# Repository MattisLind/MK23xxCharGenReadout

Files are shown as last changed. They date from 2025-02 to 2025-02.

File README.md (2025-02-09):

# Mostek MK23XX Character Generator Readout

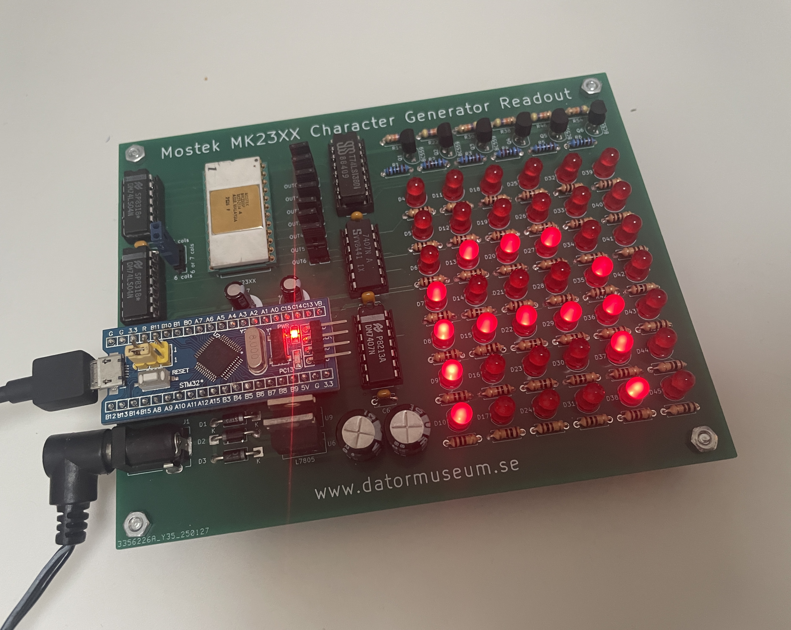
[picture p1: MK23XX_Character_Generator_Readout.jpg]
Mostek MK23XX Character Generator Readout device under opertion showing an A character


This device is used to read out the contents of early character generator MK23XX ROMs from Mostek. These devices is a bit special since they include a column counter so that the each column cannot be
accessed directly through external addressing pins.

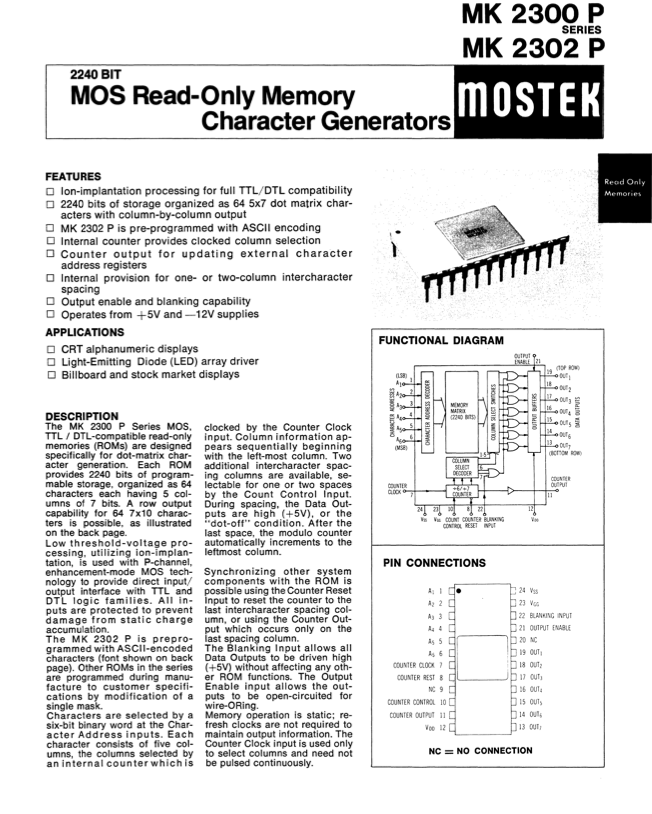
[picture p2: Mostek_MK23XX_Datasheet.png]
Mostek MK23XX Datasheet


The device has to be connected over USB (unless this section is commented out in the source code) and then it provide a dump of the contents of the ROM as hex as it cycles through all 64 characters.

```
CHAR0 COLUMN 0 VALUE 0
CHAR0 COLUMN 1 VALUE 0
CHAR0 COLUMN 2 VALUE 0
CHAR0 COLUMN 3 VALUE 0
CHAR0 COLUMN 4 VALUE 0
CHAR1 COLUMN 0 VALUE 7
CHAR1 COLUMN 1 VALUE 7
CHAR1 COLUMN 2 VALUE 7
CHAR1 COLUMN 3 VALUE 7
CHAR1 COLUMN 4 VALUE 7
CHAR2 COLUMN 0 VALUE 70
CHAR2 COLUMN 1 VALUE 70
CHAR2 COLUMN 2 VALUE 70
CHAR2 COLUMN 3 VALUE 70
CHAR2 COLUMN 4 VALUE 70
```

Please note that the contents of this example ROM is active low so that a binary 0 indicate a lit pixel. Depending if the outputs are active low or high the output driver can be 7407 or 7406 respectively.

## PCB

The first PCB had too small holes for the 24 pin ROM socket so it was not possible to fit a ZIF socket. I revised the PCB so that the new PCB have 1.0 mm holes rather than 0.8 mm. I think that this should work better but have not ordered any PCB to check. 

## Software

The software is an Arduino sketch. I have been using [Arduino Core STM32](https://github.com/stm32duino/Arduino_Core_STM32) library. The Bluepill is a STM32F103C6 and it is set to have USB enabled with serial support 

There is a #define SCROLL which can be set to either 0 or 1 if one want the fancier soft scroll rather than just showing each character.

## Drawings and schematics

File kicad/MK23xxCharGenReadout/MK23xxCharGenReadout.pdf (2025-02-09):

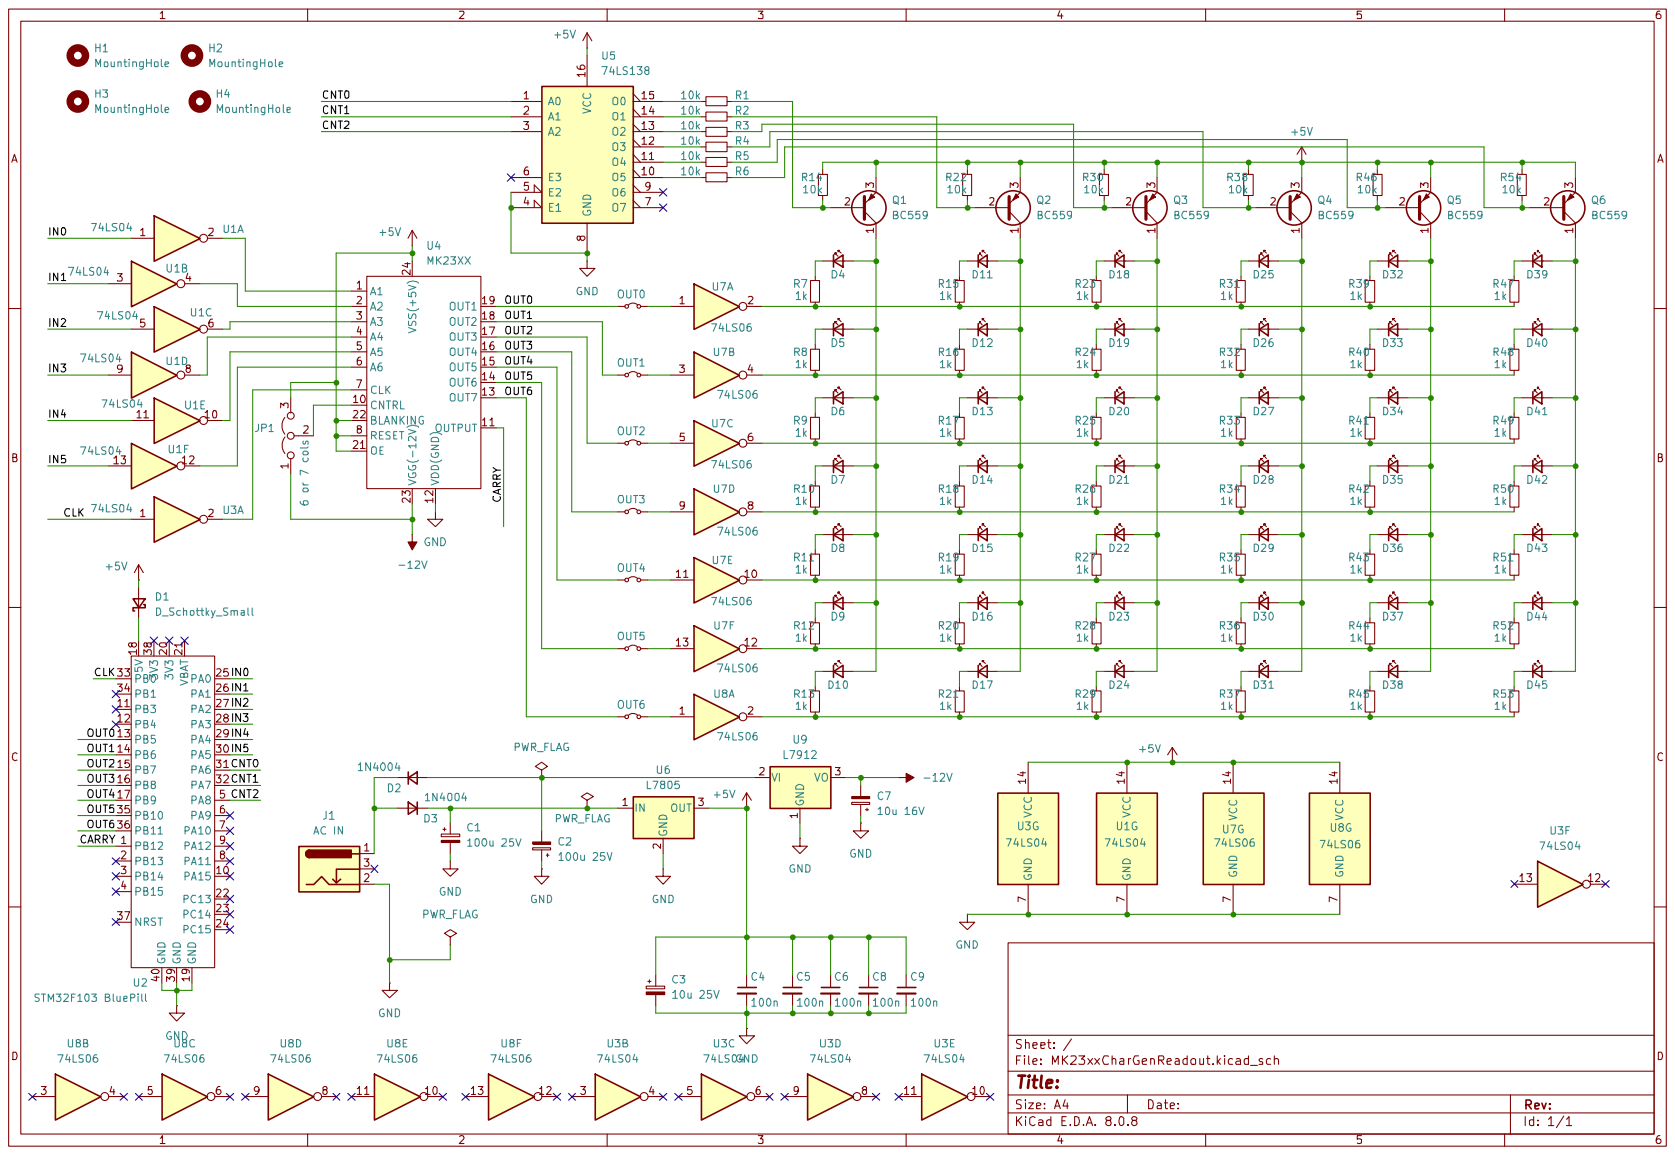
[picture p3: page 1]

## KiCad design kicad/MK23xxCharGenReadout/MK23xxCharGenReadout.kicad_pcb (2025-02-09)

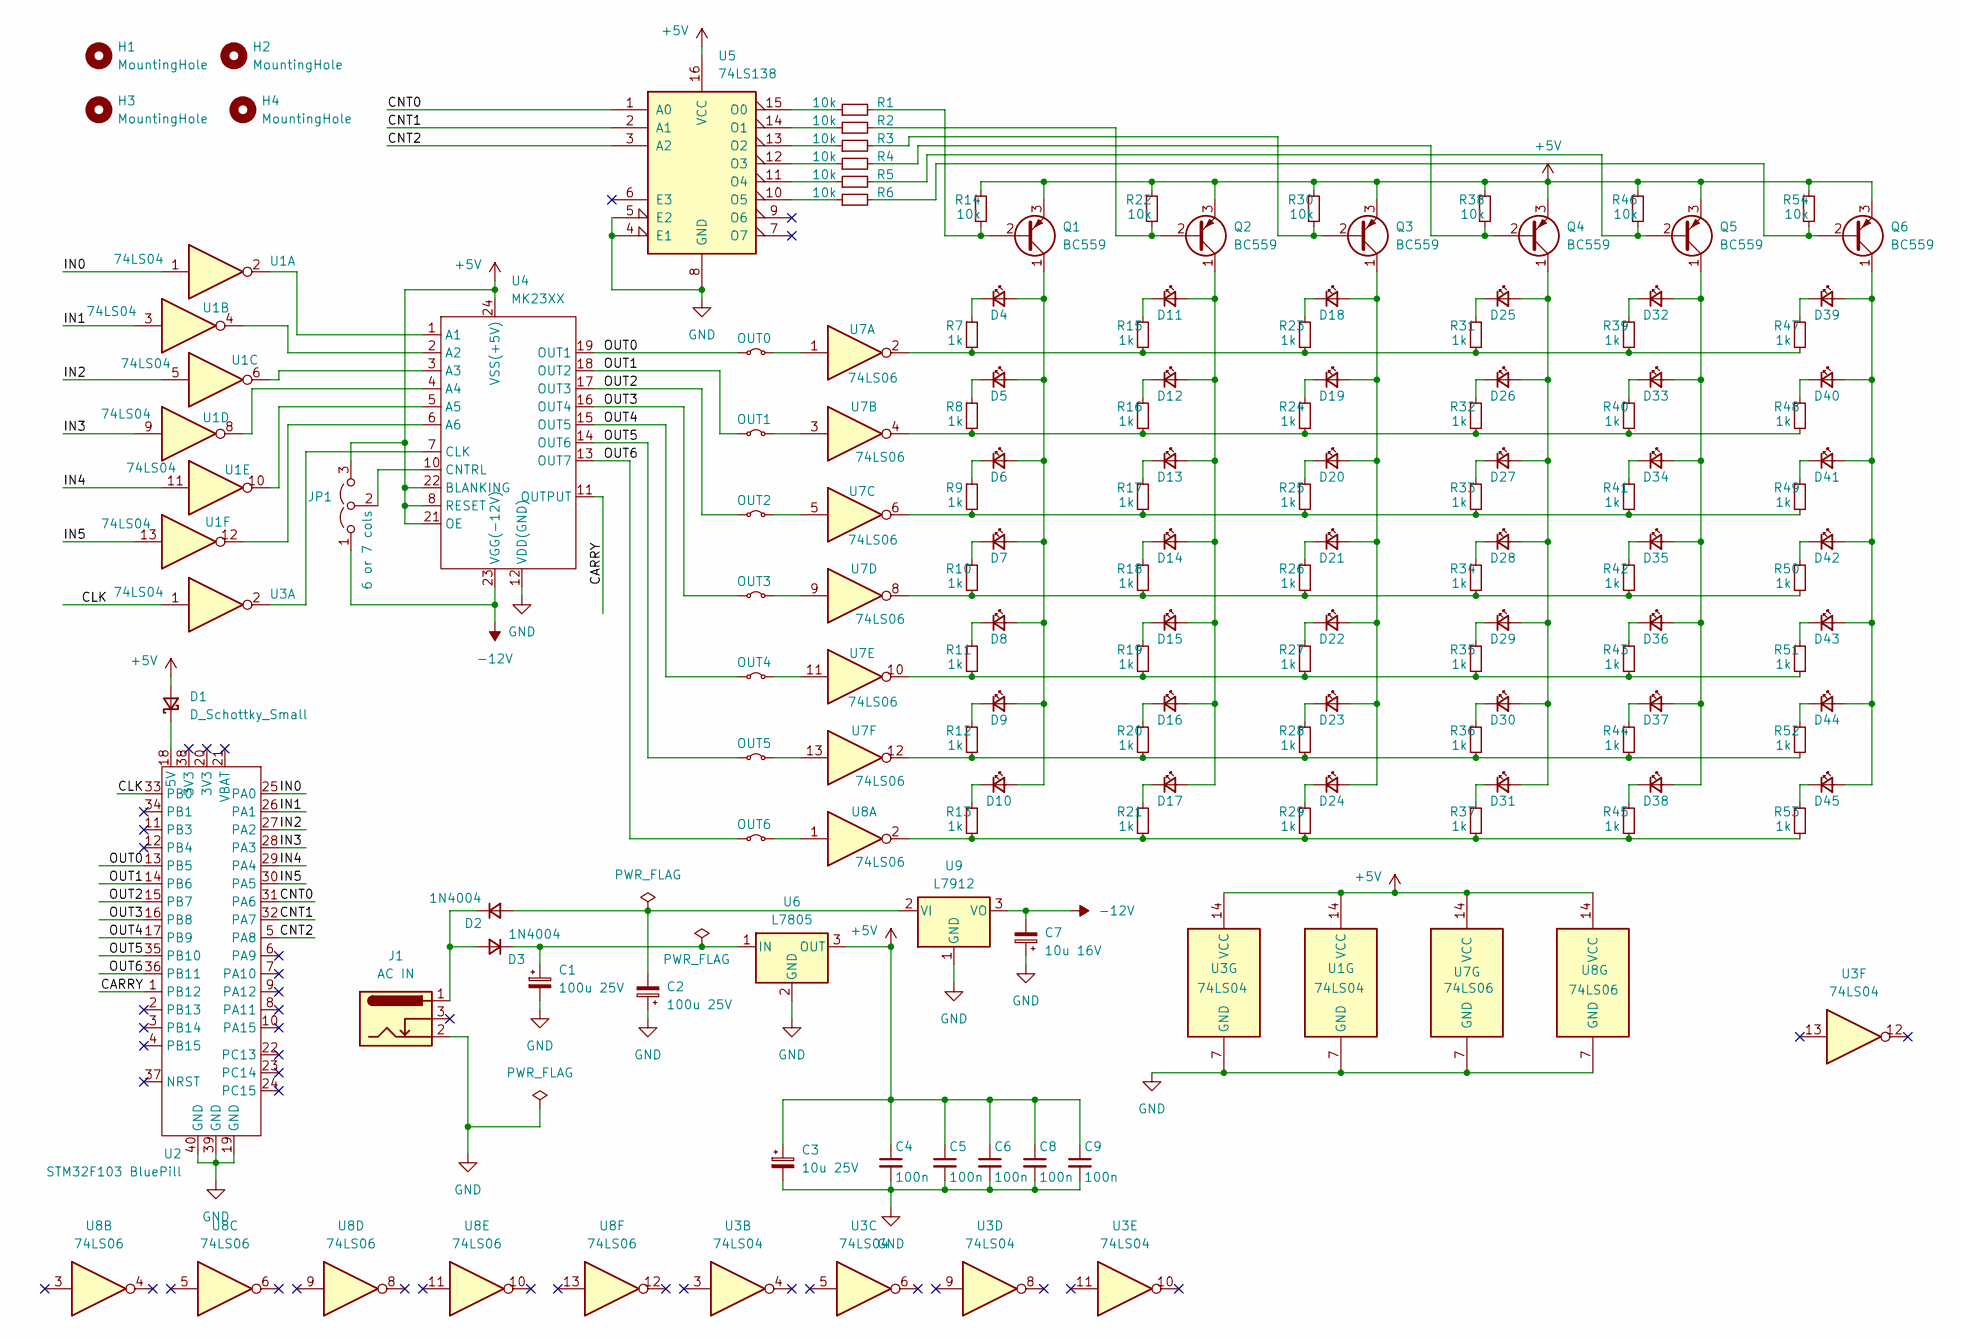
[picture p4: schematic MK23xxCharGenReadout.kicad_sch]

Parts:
C1, C2: 100u 25V; CP_Radial_D8.0mm_P5.00mm
C3: 10u 25V; CP_Radial_D7.5mm_P2.50mm
C4, C5, C6, C8, C9: 100n; C_Disc_D5.0mm_W2.5mm_P5.00mm
C7: 10u 16V; CP_Radial_D7.5mm_P2.50mm
D1: D_Schottky_Small; D_DO-41_SOD81_P10.16mm_Horizontal
D2, D3: 1N4004; D_DO-41_SOD81_P10.16mm_Horizontal
D4, D5, D6, D7, D8, D9, D10, D11, D12, D13, D14, D15, D16, D17, D18, D19, D20, D21, D22, D23, D24, D25, D26, D27, D28, D29, D30, D31, D32, D33, D34, D35, D36, D37, D38, D39, D40, D41, D42, D43, D44, D45: LED_Small; LED_D5.0mm
H1, H2, H3, H4: MountingHole; MountingHole_3.2mm_M3
J1: AC IN; BarrelJack_Kycon_KLDX-0202-xC_Horizontal
JP1: 6 or 7 cols; PinHeader_1x03_P2.54mm_Vertical
OUT0, OUT1, OUT2, OUT3, OUT4, OUT5, OUT6: Jumper_2_Small_Bridged; PinHeader_1x02_P2.54mm_Vertical
Q1, Q2, Q3, Q4, Q5, Q6: BC559; TO-92
R1, R2, R3, R4, R5, R6, R14, R22, R30, R38, R46, R54: 10k; R_Axial_DIN0207_L6.3mm_D2.5mm_P7.62mm_Horizontal
R7, R8, R9, R10, R11, R12, R13, R15, R16, R17, R18, R19, R20, R21, R23, R24, R25, R26, R27, R28, R29, R31, R32, R33, R34, R35, R36, R37, R39, R40, R41, R42, R43, R44, R45, R47, R48, R49, R50, R51, R52, R53: 1k; R_Axial_DIN0207_L6.3mm_D2.5mm_P7.62mm_Horizontal
U1, U3: 74LS04; DIP-14_W7.62mm
U2: STM32F103 BluePill; DIP-40_W15.24mm
U4: MK23XX; DIP-24_W15.24mm
U5: 74LS138; DIP-16_W7.62mm
U6: L7805; TO-220-3_Vertical
U7, U8: 74LS06; DIP-14_W7.62mm
U9: L7912; TO-220-3_Vertical

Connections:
+5V: C3.1, C4.1, C5.1, C6.1, C8.1, C9.1, D1.2 (A), JP1.3 (B), Q1.3 (E), Q2.3 (E), Q3.3 (E), Q4.3 (E), Q5.3 (E), Q6.3 (E), R14.1, R22.1, R30.1, R38.1, R46.1, R54.1, U1.14 (VCC), U3.14 (VCC), U4.8 (RESET), U4.21 (OE), U4.22 (BLANKING), U4.24 (VSS(+5V)), U5.16 (VCC), U6.3 (OUT), U7.14 (VCC), U8.14 (VCC)
-12V: C7.2, JP1.1 (A), U4.23 (VGG(-12V)), U9.3 (VO)
/CARRY: U2.1 (PB12), U4.11 (OUTPUT)
/CLK: U2.33 (PB0), U3.1
/CNT0: U2.31 (PA6), U5.1 (A0)
/CNT1: U2.32 (PA7), U5.2 (A1)
/CNT2: U2.5 (PA8), U5.3 (A2)
/IN0: U1.1, U2.25 (PA0)
/IN1: U1.3, U2.26 (PA1)
/IN2: U1.5, U2.27 (PA2)
/IN3: U1.9, U2.28 (PA3)
/IN4: U1.11, U2.29 (PA4)
/IN5: U1.13, U2.30 (PA5)
/OUT0: OUT0.1 (A), U2.13 (PB5), U4.19 (OUT1)
/OUT1: OUT1.1 (A), U2.14 (PB6), U4.18 (OUT2)
/OUT2: OUT2.1 (A), U2.15 (PB7), U4.17 (OUT3)
/OUT3: OUT3.1 (A), U2.16 (PB8), U4.16 (OUT4)
/OUT4: OUT4.1 (A), U2.17 (PB9), U4.15 (OUT5)
/OUT5: OUT5.1 (A), U2.35 (PB10), U4.14 (OUT6)
/OUT6: OUT6.1 (A), U2.36 (PB11), U4.13 (OUT7)
GND: C1.2, C2.1, C3.2, C4.2, C5.2, C6.2, C7.1, C8.2, C9.2, J1.2, U1.7 (GND), U2.19 (GND), U2.39 (GND), U2.40 (GND), U3.7 (GND), U4.12 (VDD(GND)), U5.4 (E1), U5.5 (E2), U5.8 (GND), U6.2 (GND), U7.7 (GND), U8.7 (GND), U9.1 (GND)
unnamed: D1.1 (K), U2.18 (5V)
unnamed: C2.2, D2.2 (A), U9.2 (VI)
unnamed: D2.1 (K), D3.2 (A), J1.1
unnamed: C1.1, D3.1 (K), U6.1 (IN)
unnamed: D4.1 (K), R7.1
unnamed: D5.1 (K), R8.1
unnamed: D6.1 (K), R9.1
unnamed: D7.1 (K), R10.1
unnamed: D8.1 (K), R11.1
unnamed: D9.1 (K), R12.1
unnamed: D4.2 (A), D5.2 (A), D6.2 (A), D7.2 (A), D8.2 (A), D9.2 (A), D10.2 (A), Q1.1 (C)
unnamed: D10.1 (K), R13.1
unnamed: D11.2 (A), D12.2 (A), D13.2 (A), D14.2 (A), D15.2 (A), D16.2 (A), D17.2 (A), Q2.1 (C)
unnamed: D11.1 (K), R15.1
unnamed: D12.1 (K), R16.1
unnamed: D13.1 (K), R17.1
unnamed: D14.1 (K), R18.1
unnamed: D15.1 (K), R19.1
unnamed: D16.1 (K), R20.1
unnamed: D17.1 (K), R21.1
unnamed: D18.2 (A), D19.2 (A), D20.2 (A), D21.2 (A), D22.2 (A), D23.2 (A), D24.2 (A), Q3.1 (C)
unnamed: D18.1 (K), R23.1
unnamed: D19.1 (K), R24.1
unnamed: D20.1 (K), R25.1
unnamed: D21.1 (K), R26.1
unnamed: D22.1 (K), R27.1
unnamed: D23.1 (K), R28.1
unnamed: D24.1 (K), R29.1
unnamed: D25.2 (A), D26.2 (A), D27.2 (A), D28.2 (A), D29.2 (A), D30.2 (A), D31.2 (A), Q4.1 (C)
unnamed: D25.1 (K), R31.1
unnamed: D26.1 (K), R32.1
unnamed: D27.1 (K), R33.1
unnamed: D28.1 (K), R34.1
unnamed: D29.1 (K), R35.1
unnamed: D30.1 (K), R36.1
unnamed: D31.1 (K), R37.1
unnamed: D32.2 (A), D33.2 (A), D34.2 (A), D35.2 (A), D36.2 (A), D37.2 (A), D38.2 (A), Q5.1 (C)
unnamed: D32.1 (K), R39.1
unnamed: D33.1 (K), R40.1
unnamed: D34.1 (K), R41.1
unnamed: D35.1 (K), R42.1
unnamed: D36.1 (K), R43.1
unnamed: D37.1 (K), R44.1
unnamed: D38.1 (K), R45.1
unnamed: D39.2 (A), D40.2 (A), D41.2 (A), D42.2 (A), D43.2 (A), D44.2 (A), D45.2 (A), Q6.1 (C)
unnamed: D39.1 (K), R47.1
unnamed: D40.1 (K), R48.1
unnamed: D41.1 (K), R49.1
unnamed: D42.1 (K), R50.1
unnamed: D43.1 (K), R51.1
unnamed: D44.1 (K), R52.1
unnamed: D45.1 (K), R53.1
unnamed: JP1.2 (C), U4.10 (CNTRL)
unnamed: OUT0.2 (B), U7.1
unnamed: OUT1.2 (B), U7.3
unnamed: OUT2.2 (B), U7.5
unnamed: OUT3.2 (B), U7.9
unnamed: OUT4.2 (B), U7.11
unnamed: OUT5.2 (B), U7.13
unnamed: OUT6.2 (B), U8.1
unnamed: Q1.2 (B), R1.2, R14.2
unnamed: Q2.2 (B), R2.2, R22.2
unnamed: Q3.2 (B), R3.2, R30.2
unnamed: Q4.2 (B), R4.2, R38.2
unnamed: Q5.2 (B), R5.2, R46.2
unnamed: Q6.2 (B), R6.2, R54.2
unnamed: R10.2, R18.2, R26.2, R34.2, R42.2, R50.2, U7.8
unnamed: R11.2, R19.2, R27.2, R35.2, R43.2, R51.2, U7.10
unnamed: R12.2, R20.2, R28.2, R36.2, R44.2, R52.2, U7.12
unnamed: R13.2, R21.2, R29.2, R37.2, R45.2, R53.2, U8.2
unnamed: R7.2, R15.2, R23.2, R31.2, R39.2, R47.2, U7.2
unnamed: R8.2, R16.2, R24.2, R32.2, R40.2, R48.2, U7.4
unnamed: R9.2, R17.2, R25.2, R33.2, R41.2, R49.2, U7.6
unnamed: U1.2, U4.1 (A1)
unnamed: U1.4, U4.2 (A2)
unnamed: U1.6, U4.3 (A3)
unnamed: U1.8, U4.4 (A4)
unnamed: U1.10, U4.5 (A5)
unnamed: U1.12, U4.6 (A6)
unnamed: U3.2, U4.7 (CLK)
unnamed: R1.1, U5.15 (O0)
unnamed: R2.1, U5.14 (O1)
unnamed: R3.1, U5.13 (O2)
unnamed: R4.1, U5.12 (O3)
unnamed: R5.1, U5.11 (O4)
unnamed: R6.1, U5.10 (O5)

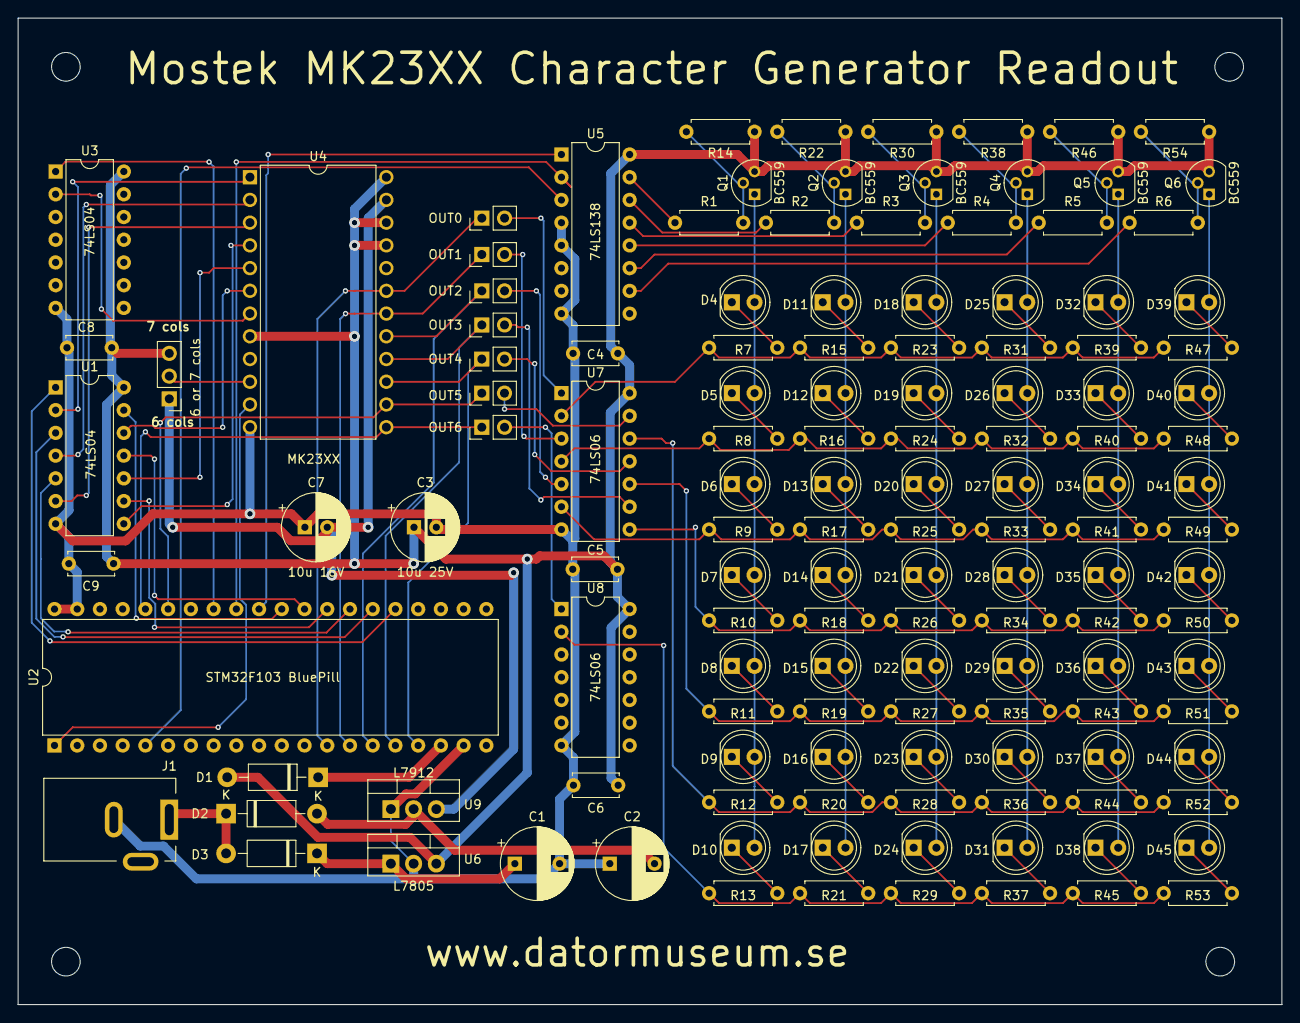
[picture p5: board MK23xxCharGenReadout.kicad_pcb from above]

Board: 2 copper layers, 141.2 x 110.2 mm, 136 parts (0 on the bottom side), 107 nets.

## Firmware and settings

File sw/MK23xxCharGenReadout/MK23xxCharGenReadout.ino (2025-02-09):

/*
  Sketch to read out and display the contents of a Mostek MK23xx Character Generatror ROM

  Mattis Lind 2025
*/

#define CLK PB0
#define CNT0 PA6
#define CNT1 PA7
#define CNT2 PA8
#define CARRY PB12
#define OUT0 PB5
#define OUT1 PB6
#define OUT2 PB7
#define OUT3 PB8
#define OUT4 PB9
#define OUT5 PB10
#define OUT6 PB11
#define IN0 PA0
#define IN1 PA1
#define IN2 PA2
#define IN3 PA3
#define IN4 PA4
#define IN5 PA5
#define SCROLL 0

void inOutput(int in) {
  digitalWrite(IN0, in & 1);
  digitalWrite(IN1, (in & 2)>>1);
  digitalWrite(IN2, (in & 4)>>2);
  digitalWrite(IN3, (in & 8)>>3);
  digitalWrite(IN4, (in & 16)>>4);
  digitalWrite(IN5, (in & 32)>>5);
}

int outRead() {
  return (digitalRead(OUT0)) | 
        ((digitalRead(OUT1)) << 1) |
        ((digitalRead(OUT2)) << 2) |
        ((digitalRead(OUT3)) << 3) |
        ((digitalRead(OUT4)) << 4) |
        ((digitalRead(OUT5)) << 5) |
        ((digitalRead(OUT6)) << 6);
}

void countOutput(int cnt) {
  int val;
  
  switch (cnt) {
    case 0:
      GPIOA ->ODR &= ~(GPIO_ODR_ODR6 | GPIO_ODR_ODR7 | GPIO_ODR_ODR8);
      break;
    case 1:
      GPIOA ->ODR &= ~(GPIO_ODR_ODR7 | GPIO_ODR_ODR8);
      GPIOA ->ODR |= (GPIO_ODR_ODR6);
      break;
    case 2:
      GPIOA ->ODR |= (GPIO_ODR_ODR7);
      GPIOA ->ODR &= ~(GPIO_ODR_ODR6 | GPIO_ODR_ODR8);   
      break;
    case 3:
      GPIOA ->ODR |= (GPIO_ODR_ODR6 | GPIO_ODR_ODR7);
      GPIOA ->ODR &= ~(GPIO_ODR_ODR8);    
      break;
    case 4:
      GPIOA ->ODR |= (GPIO_ODR_ODR8);
      GPIOA ->ODR &= ~(GPIO_ODR_ODR6  | GPIO_ODR_ODR7 );     
      break;
    case 5:
      GPIOA ->ODR |= (GPIO_ODR_ODR6  | GPIO_ODR_ODR8);
      GPIOA ->ODR &= ~(GPIO_ODR_ODR7 );    
      break;
    case 6:
      GPIOA ->ODR |= (GPIO_ODR_ODR7  | GPIO_ODR_ODR8);
      GPIOA ->ODR &= ~(GPIO_ODR_ODR6 );    
      break;      
    default:
      GPIOA ->ODR |= (GPIO_ODR_ODR6  | GPIO_ODR_ODR8 | GPIO_ODR_ODR7);   
      break;
  }
  
}

int i;
int j;
int character;
int k;
int start;

// the setup function runs once when you press reset or power the board
void setup() {
  pinMode(CNT0, OUTPUT);
  pinMode(CNT1, OUTPUT);
  pinMode(CNT2, OUTPUT);  
  pinMode(IN0, OUTPUT);
  pinMode(IN1, OUTPUT);
  pinMode(IN2, OUTPUT);
  pinMode(IN3, OUTPUT);
  pinMode(IN4, OUTPUT);
  pinMode(IN5, OUTPUT);
  pinMode(OUT0, INPUT);     
  pinMode(OUT1, INPUT); 
  pinMode(OUT2, INPUT); 
  pinMode(OUT3, INPUT); 
  pinMode(OUT4, INPUT); 
  pinMode(OUT5, INPUT); 
  pinMode(OUT6, INPUT);   
  pinMode(CARRY, INPUT);
  pinMode(CLK, OUTPUT);      
  i=0;
  j=0;
  k=0;
  character = 0;
  start=5;
  Serial.begin(9600);
  while (!Serial) {
    ;  // wait for serial port to connect. Needed for native USB port only
  }
  Serial.println("MK23XX CHAR GEN BIT MAP");
}


#define LEDPWM 100
#define CLK_LOW 500
#define CLK_HIGH 500
// the loop function runs over and over again forever
void loop() {
  //
  countOutput(7);
  digitalWrite(CLK, HIGH); 
  countOutput(7);
  delayMicroseconds(CLK_HIGH-LEDPWM); 
  countOutput(i);

  i++; 
  if (i>5) i=0; 
  if (k==0 && start == 0 && i > 0) {
    Serial.print("CHAR");
    Serial.print(character,HEX);
    Serial.print(" COLUMN ");
    Serial.print(((i-1)>=0)?(i-1):5);
    Serial.print(" VALUE ");
    Serial.print(outRead(), HEX);
    Serial.println();
  }

  delayMicroseconds(LEDPWM); 
  countOutput(6);
  digitalWrite(CLK, LOW);
  if (digitalRead(CARRY) == HIGH) {
    if (k>20) {
      start--;
      if (start<0) {
        start=5;
        if (character > 62) {
          character = 0;
        } else {
          character++;
        }
      }
      k=0;
    } else {
      k++;
    }
    if (SCROLL) {
      i = start;
    } else {
      i=0;
    }
  } 

  if (SCROLL) {
    if (i<start) {
      inOutput(~(character & 0x3f));  
    } else {
      inOutput(~((character+1) & 0x3f));  
    }
  } else {
    inOutput(~(character & 0x3f)); 
  } 

  delayMicroseconds(CLK_LOW);        
}

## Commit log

2025-01-31 Add files.
    [MK23xxCharGenReadout-B_Cu.gbr, MK23xxCharGenReadout-B_Mask.gbr, MK23xxCharGenReadout-B_Paste.gbr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]
2025-02-09 Added schematic pdf file.
2025-02-09 Increased size of holes for 24 pin socket to allow for ZIF socket.
    [MK23xxCharGenReadout-B_Cu.gbr, MK23xxCharGenReadout-B_Mask.gbr, MK23xxCharGenReadout-B_Paste.gbr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]
2025-02-09 Correcting values in the schematic.
    [MK23xxCharGenReadout.kicad_sch]
